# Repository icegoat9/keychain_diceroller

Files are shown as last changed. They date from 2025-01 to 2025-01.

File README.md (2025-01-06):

## Keychain Diceroller

I recently bought a board game that was missing a specialized die. Clearly the easiest solution to that problem was to build a little electronic keychain 'dice roller'.

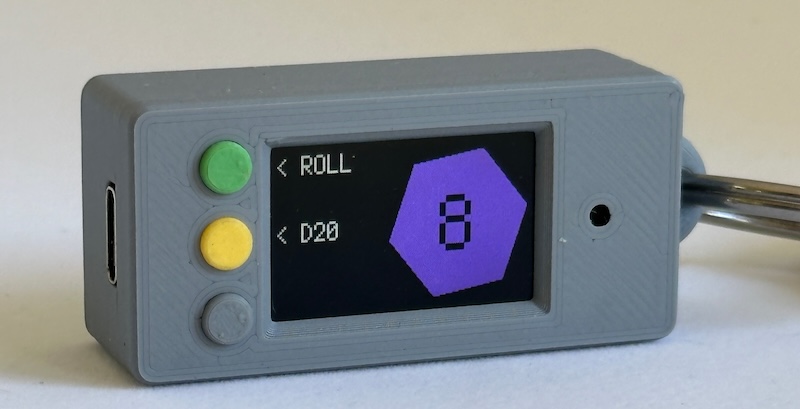
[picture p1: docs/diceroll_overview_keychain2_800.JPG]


<!-- demo video -->
https://github.com/icegoat9/diceroll_feather/assets/85364179/eb14111a-678f-439f-8b59-4e56392dd97d

**Features:**
* Press top button to roll a die
* Press middle button to cycle through a custom list of dice to roll (here: D3, D6, D10, D20, D100)
* Numbers on dice can be configured to start at 1 (D6, D20) or 0 (D10, D100)
* Dice can also display symbols (e.g. D3 rolls a "-", "O", or "+", for a specific game)
* Small battery that charges over USB-C port
* Standby battery life of many months (the system goes into a light sleep mode to save power after a short period of inactivity, and a deeper sleep mode after minutes of inactivity).
## Hardware

* Adafruit [ESP32-S3 Feather with reverse-mounted TFT](https://www.adafruit.com/product/5691)
* Various batteries, most recently [Lithium Ion Polymer Battery, 3.7V 400mAh](https://www.adafruit.com/product/3898)
* For cleaner packaging (requiring minor desoldering), JST surface mount straight header e.g. [JST B2B-PH-SM4-TB](https://www.digikey.com/en/products/detail/jst-sales-america-inc/B2B-PH-SM4-TB)
* [Case](case/) (3D printed, with button inserts)
  * Nominally, 2 each M2 and M2.5 BHCS fasteners, but a few dots of superglue may be easier...

## Development Log

Hooking together some parts I had laying around to experiment with this particular SPI-interface display and the CircuitPython ecosystem:

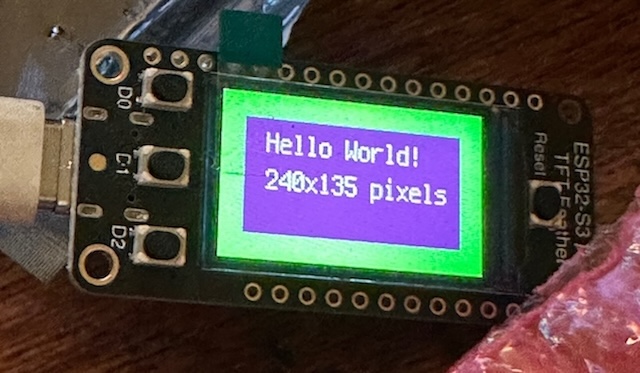
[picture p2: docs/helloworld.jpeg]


In a few hours I had a working battery-powered prototype I could use:

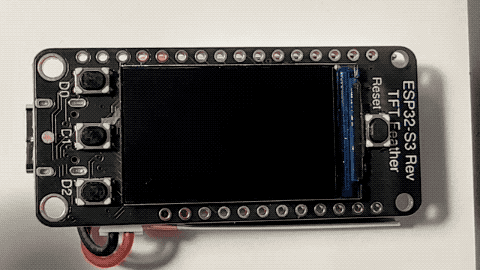
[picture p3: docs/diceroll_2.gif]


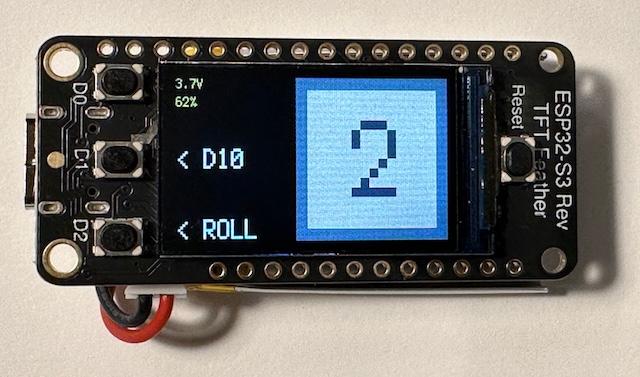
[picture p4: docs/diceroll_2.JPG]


However, the battery drained in about an hour-- that's not especially useful. I put the project on the back burner for a few weeks, but wrote some code to experiment with different power savings such as dimming or turning off the display, disabling unused peripherals, and various ESP32 sleep modes, and left prototypes running for days and weeks to log battery level over time:

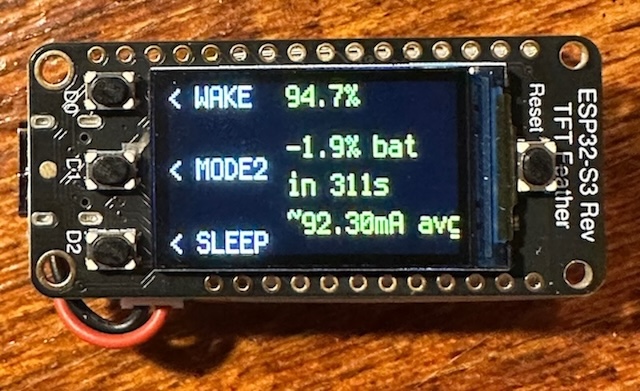
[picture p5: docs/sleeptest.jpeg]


For cleaner packaging than just "a PCB double-stick-taped to an unprotected LiPo battery", I prototyped a few cases. It was inconvenient that the battery needs to enter on the side of the PCB, so I carefully desoldered the right angle battery connector and replaced it with a straight through connector (I also desoldered the unused Stemma QT I2C connector on the back of the Feather to make more space for the battery):
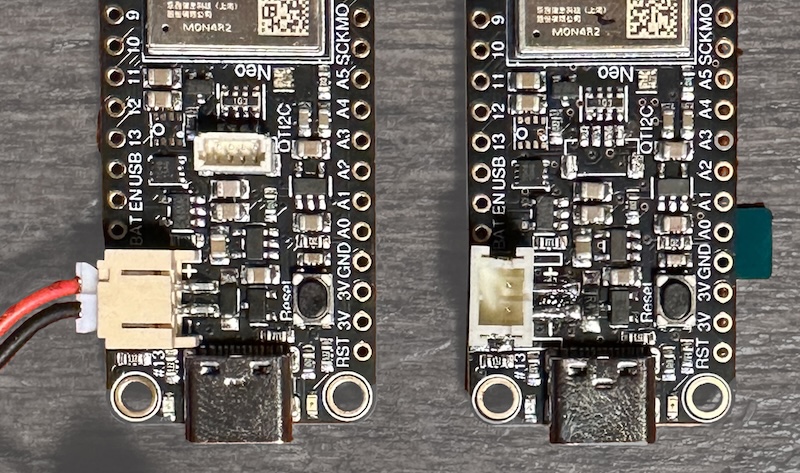
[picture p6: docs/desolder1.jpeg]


**CAUTION:** I had to bend the pins on this straight-through connector 180 degrees (shown below after bending), because soldering the off-the-shelf straight-through connector into the existing location would have swapped + and - relative to the right angle connector, frying the board! Be careful that the polarization notch on the connector is consistent between the removed right-angle and replacement connector:
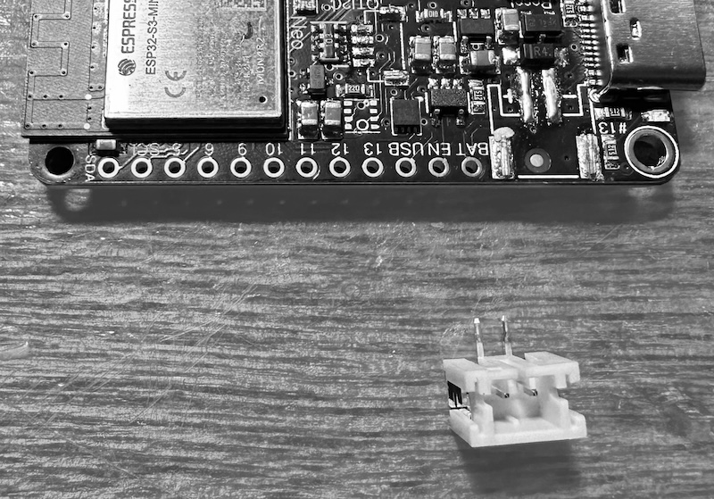
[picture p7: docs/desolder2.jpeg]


First PCB sandwich with a narrow 400mAh LiPo battery:
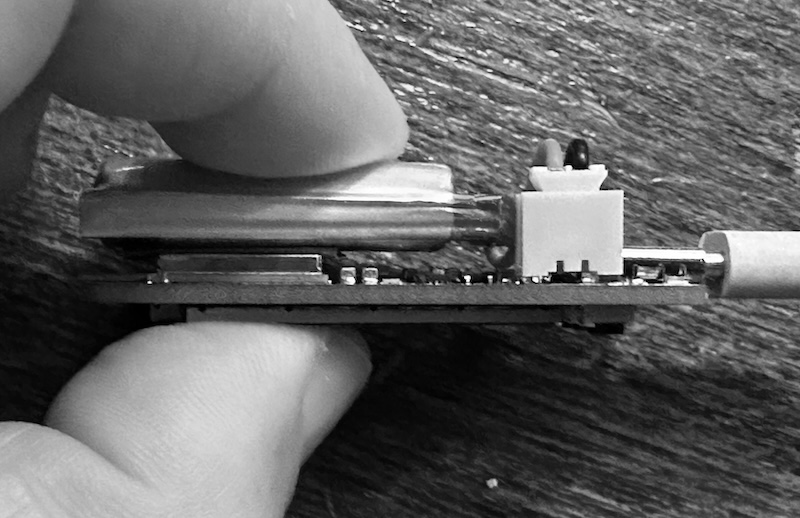
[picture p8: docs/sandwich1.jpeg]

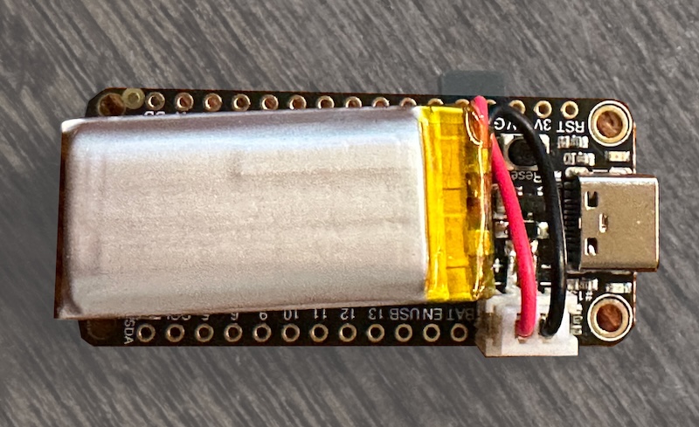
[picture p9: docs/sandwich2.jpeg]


A quick case design, 3D printed by a friend in PLA ("a polyester made from fermented plant starch"):
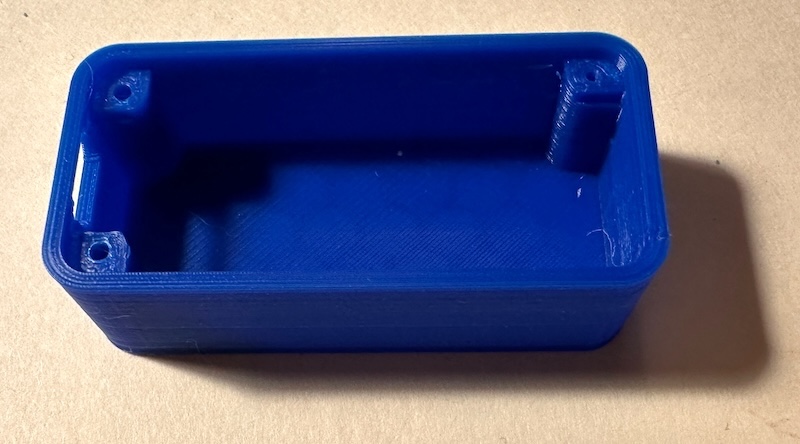
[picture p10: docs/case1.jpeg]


Tapping fine threads directly into 3D printed plastics is a bit sketchy as a design practice compared to pressing in metal inserts, but if you undersize the holes a bit, use a jig, and have deep enough threads, it's possible... and I have a finished-enough portable device:
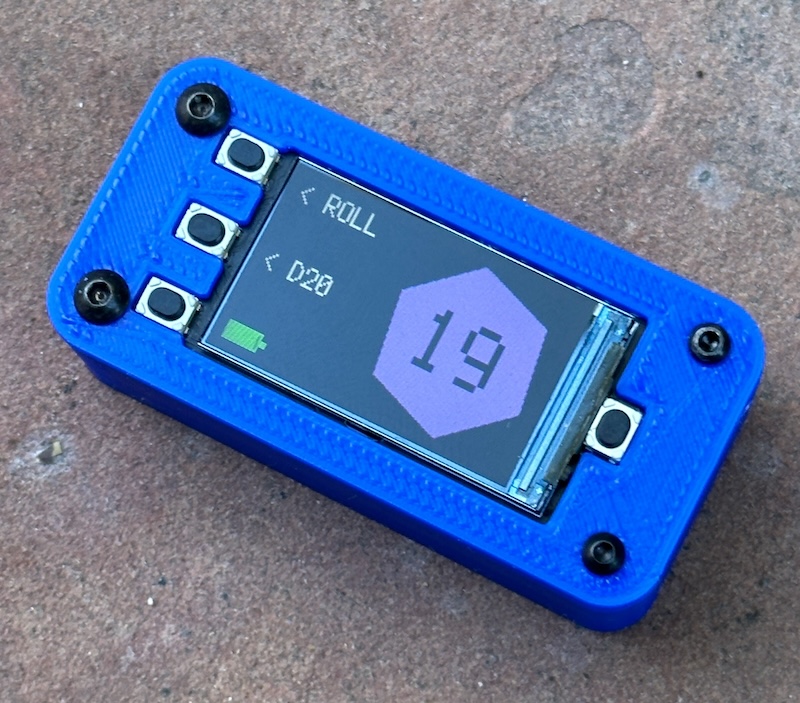
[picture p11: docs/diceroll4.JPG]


Finally, I came back to the software to add some light animations, a battery indicator, and a hybrid sleep mode for what should be months of battery life. This was a satisfying small project.

**v2 Update:**  

I put a bit more time into the project, mostly to design the new enclosure with buttons shown at the top of this page ([more details on the case design](case/)). I also took that opportunity to clean up and remove unused or debugging code and add a smarter battery icon.

The standby battery life seems excellent in practice-- over the past few months I've used this from time to time when playing a game (including the solo board game "Gloomhaven: Buttons & Bugs", which needs a special - / 0 / + die), and the battery finally ran down and needed a recharge after about six months (though it spent several of those months sitting unused).

## Installation

* Configure the Feather with CircuitPython 9.x
* Copy diceroll.py, code.py, and the lib/ folder onto the Feather

## Possible Future Work

This is 'good enough' for now, and I was trying to keep this a quick side project-- I don't expect to put more time into this unless inspiration strikes, but a few ideas I could come back to some day:

* ~~Revise the enclosure to cover the edges of the display, add button caps, and be less boxy overall~~
* ~~Buy my own 3D printer rather than depending on a friend's or paying every time I want to revise a design...~~
* Look into improving the performance of drawing vector shapes for a faster 'die rolling' animation
* Dig deeper into ESP32 sleep modes and ways to extend battery life outside of deep sleep-- battery life is already great, but perhaps this could enable an even smaller battery and package
* Add the ability to roll multiple dice at once (e.g. 2D6), including some visualization of each die, not just a total
* Add a whole configuration mode / menu (entered by the third button), to let you adjust parameters such as the sleep delay, the animation speed, the list of dice options, and so on, without having to edit and reload code
  * Persist all of these settings in backup RAM through deep sleeps, or maybe even to onboard flash when power is lost *(I don't really need any of these features, but menu+configuration+persistence could be useful in a future project...)*

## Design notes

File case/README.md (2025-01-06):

This folder contains the current STL files for three case variants:
1. A simple case variant that leaves some of the PCB exposed
2. A case with button inserts and rear fasteners for a cleaner look (note: tapping tiny threads into a PLA 3D print of this is very difficult-- I may redo in a different material or redesign to use press-in threaded inserts)
3. A quick variant on case #2 but with pins, to be glued together (simpler than dealing with threads for now)

## Details

A few steps from along the way...

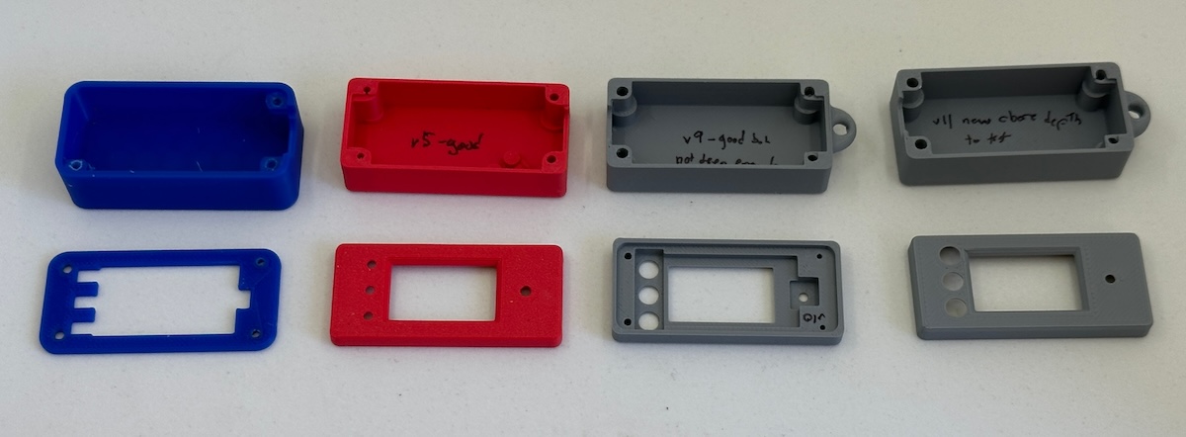
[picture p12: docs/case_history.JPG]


Design #1 is the simple case I got a friend to 3D print. It looked good enough:



Months later when I picked up my own 3D printer I was inspired to iterate on a design with button inserts and rear-mount fasteners:

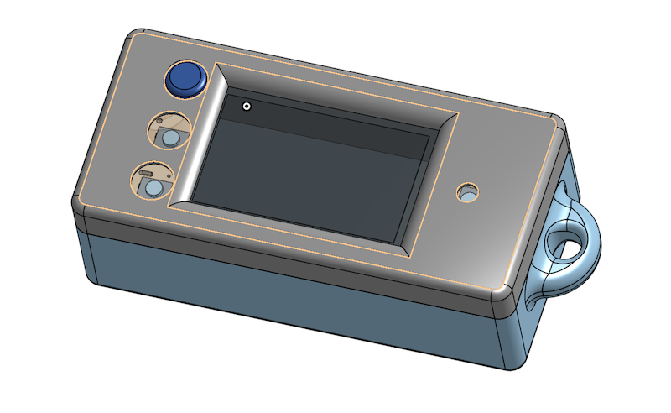
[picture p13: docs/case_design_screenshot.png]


The tolerances on a display's active pixel region relative to the edge of the glass or the display's mounting can be a challenge to design around in a volume product. For a one-off prototype it's easy enough to just display a test pattern and revise the part design until it lines up.

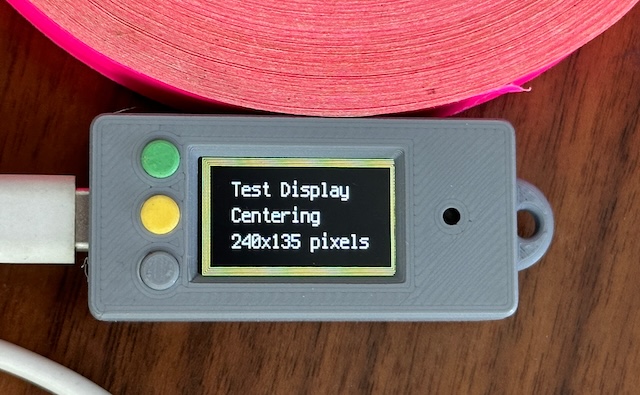
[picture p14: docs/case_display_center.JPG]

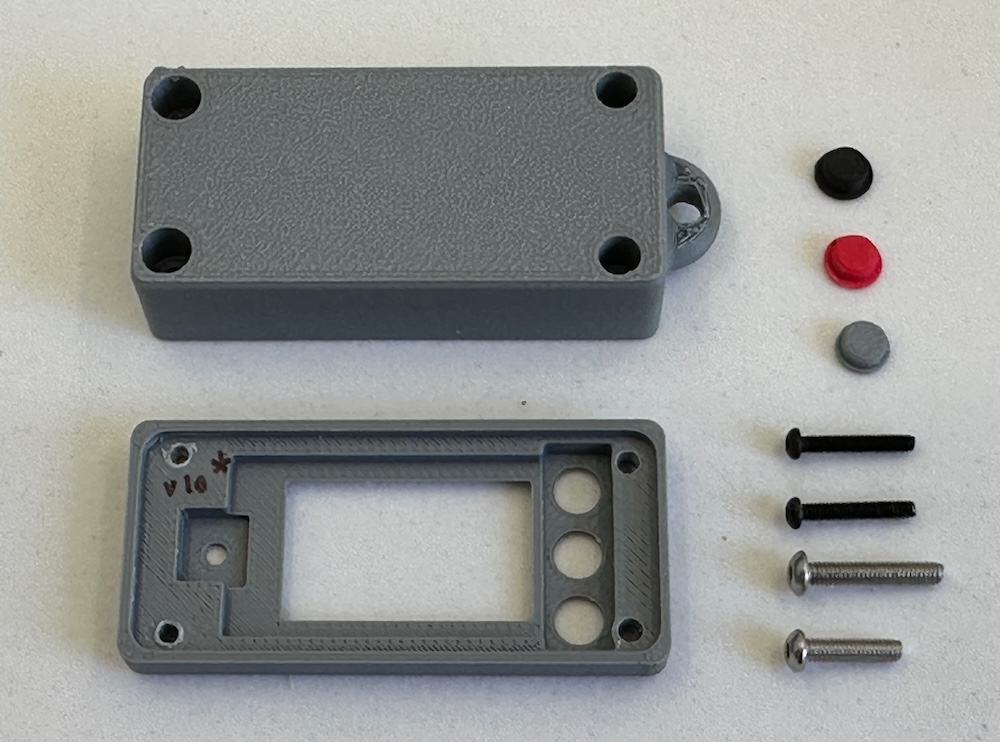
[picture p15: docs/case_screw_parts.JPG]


This case mostly works, but tapping M2 and M2.5 threads into 3D printed PLA is... not reliable, especially into these shallow blind holes. I have an M2.5 bottoming tap but don't have the equivalent in M2, and went through three copies of the top plate before I got 3/4 of the threads tapped well enough that it would assemble. Then I realized I was missing matching black oxide fasteners in the correct lengths.

I didn't want to wait to get new hardware, so I made a minor variant on it, with locating pins on the bottom piece that the PCB sits on rather than holes for screws. With a thin bead of cyanoacrylate it came together nicely, I'll just have to break it open if I ever want to service it. I could design a version with more robust heat-set threaded inserts, but it's not worth the time for this one-off.



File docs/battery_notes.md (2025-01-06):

### Battery usage experiments / scratchpad

Testing with a 420mAh LiPo battery (plan to use an even smaller one) using the MAX1704x i2c battery fuel gauge reported values:

With display on and active (Neopixel power is always off), presumably high power draw:
* 63% at 6:17pm
* 19% at 6:30pm
* Rough extrapolation (if battery meter and capacity are correct) suggests 44% drain / 13min = 184 mAh / 13min, ~850 mA!?
* At this high discharge rate (> 1C) using a smaller battery will be an issue...

With display and I2C powered down (but not using any microprocessor sleep mode, and WiFi / Bluetooth may be on in background? unclear):
* 39% at 5:15pm
* 27% at 5:28pm
* 25% at 5:30pm
* Rough extrapolation (if battery meter and capacity are correct) suggests 56% drain / hour or 235 mAh / hour = 235 mA!?
* At this moderately high discharge rate (~0.5C for this battery), using a much smaller battery may be an issue

Using microprocessor sleep modes (see [CircuitPython reference](https://learn.adafruit.com/deep-sleep-with-circuitpython/alarms-and-sleep)):

With microprocessor in light sleep (which should power down WiFi as well), and display and I2C powered down:
* 18% at 6:31pm
* "18%" at 6:35pm? though maybe battery meter hasn't kept up, if I2C power is down does that mean it's not tracking? hmm...
* 8% at 7:09pm
* This suggests 10% / 38min or 16% drain / hour or 66 mAh drain / hour, ~66mA!? (significantly higher than expected for sleep mode, maybe there are more peripherals to turn off...)

Second test:
* 94% at 9:10pm
* 84% at 9:48pm
* Suggests ~6hr lifetime, not great (~66mA draw estimated again-- something is still a big draw)

Third test, after adding `import wifi` and `wifi.radio.enabled = False` (not sure if that will change anything vs. not importing wifi in the first place?)
* 85% at 9:53pm
* 73% at 10:21pm
* Suggests ~25%/hr discharge or ~4hr lifetime, not notably different from without those wifi lines

Another test, now with D0 as trigger / wakeup pin, and fractional percent reporting
* 2:44pm 93.7% (surprisingly high given we were just at 69% recently and only briefly plugged in, I'm skeptical at first that it's this high)
* 3:15pm 76.3% (= 17.4% in 31min or about 35% capacity / hr or ~140mA estimated!? unless previous capacity was artificially high)
* 3:26pm 70.3$ (= 6% in 11min or ~36% / hr, again, hmm)

With microprocessor in deep sleep, and display and I2C powered down: (temporary test w/ D0 as wake pin instead of D2 for deep sleep...)
* 70% at 10:25pm 4/22
* 69% at 10:55pm (ooh, more promising...)
* 69% at 7:38am 4/23 (aha! still very long life... assuming battery gauge is still working... does it need more time to register?)
* 69% at 10:16am and 11:40am and 12:42pm and 2:30pm ! -- then stopped test. Not convinced I'm getting good data? TBD

Further sleep testing with dedicated test_power_usage.py: (**see photos taken 2024-04-23 of displayed results**):
* S0: ~107 mA
* S1: ~150 mA!? (doesn't make sense that this would be higher than S0... but only tested over the course of a few minutes, but maybe it's the S0 that's low)
* S2: ~130 mA!? averaged over 2400s (consistent with some earlier tests)

Further testing after recharging battery to near full
* S0: n/a (high, 100mA or more)
* S1: ~80mA? (but over just 5min so not much battery% delta to work with) 
* S2: mA? (but over just 5min so not much battery% delta to work with) 
* S3: mA? 

2024-04-27 long-running battery study involving systems waking themselves up every 30-60min to log battery state to on-board Flash (also means we don't need to directly depend on battery charge meter being correct, as we'll see when the device drains enough to stop logging):
* One device with 420mAh battery set to deep sleep for 1 hour, wake up for 1 second (plus boot-up so ~5s) and log to flash
  * Lasted multiple days, so left running
* One device with 400mAh battery set to light sleep (which has seemed ineffective) with TFT and I2C off for 30min, wake up for 1s to log to flash, repeat
  * Still only lasted 3.5 hours of light sleep

2024-May long-running battery study, with system that deep sleeps and wakes once an hour to log battery to on-board Flash, with pinAlarm also enabled (though not used) for comparable test to diceroll trinket:
* 420 mAh battery lost 14% in 20 days, suggesting months of deep sleep

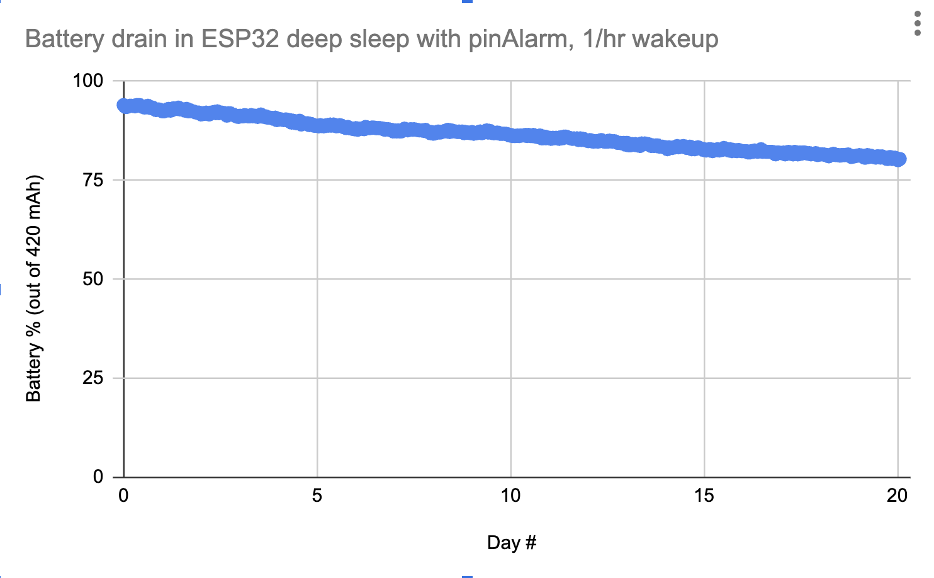
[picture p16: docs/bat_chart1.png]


The same test device was still alive as of ~early July (not used for past month), and was at ~50% battery?, so we do have many months of deep sleep if not in use, though it's not running identical code.

### Battery Packaging Dimensions

Feather relevant dimensions:
* 2.0" x 0.9" outer dimensions
* Two mounting holes are at 0.7" spacing, and are 3mm diameter holes (M2.5 or #4-40 screw), the other two are for M2 screws and are spaced differently but 1.8" away
* So, the rectangle fully inside of mounting holes in both directions would be at about 1.68" x 0.58"
  * Or 2.0 x 0.58 or 1.68 x 0.9" if we want a rectangle that clears mounting holes in one of the two directions and goes to board outline in the other
* There's just 1.4" length 'beyond the battery connector to the other end of board' (since battery connector is thick and we may want to avoid)
  * If we want to clear the mounting holes as well, we lose 0.16" so would have about 1.24" x 0.9" space

Small batteries sold by Adafruit:
* 500 mAh: 1.15 x 1.4 x 0.19"
* 420 mAh: 1.38" x 0.94" x 0.20"
* 400 mAh 1.41" x 0.67" x 0.31" (special "narrow for between feather headers", but thicker)
* 350 mAh  1.4" x 0.8" x 0.22"
* 350 mAh short cable  1.3" x 1.0" x 0.2"
* 150 mAh  0.77" x 1.02" x 0.14"
* 100 mAh  0.45" x 1.2" x 0.15"

So, what fits fully within the "rectangle that's within the mounting hole profile in one direction, and within board in the other?
* 100, 150, 350, 400narrow

Do any fit the "downstream of battery connector between that and mounting holes of 1.24 x 0.9"?
* 100, 150

None fit downstream of Stemma QT connector without also blocking mounting holes? But 150mAh probably just fits if it blocks those two holes...

If we're willing to only use three of the four mounting holes, though, and obstruct one of the smaller mounting holes with the battery, the 400mAh narrow battery should just fit.

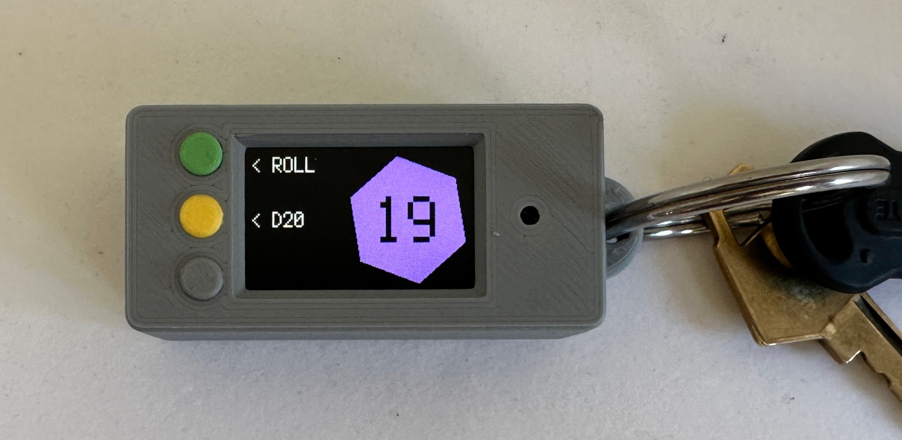
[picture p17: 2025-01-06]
docs/diceroll_overview_keychain.JPG

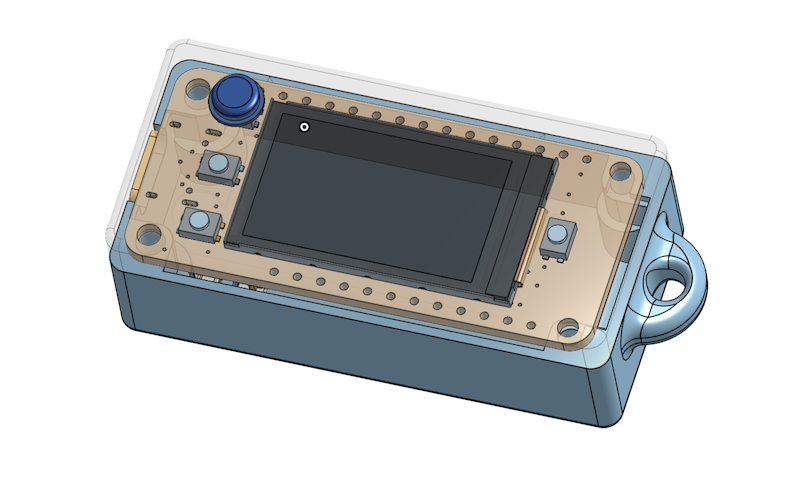
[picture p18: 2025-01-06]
docs/case_design_screenshot2.png

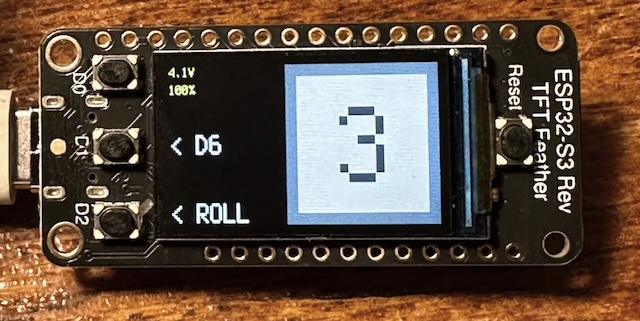
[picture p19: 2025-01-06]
docs/diceroll_1.JPG

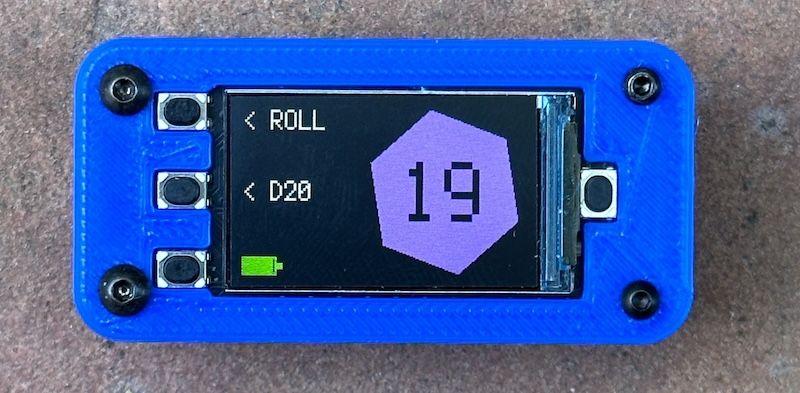
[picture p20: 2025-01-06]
docs/diceroll3.JPG

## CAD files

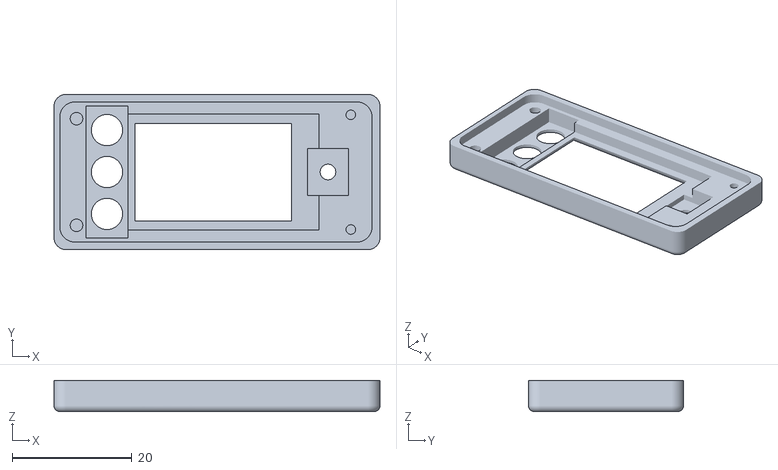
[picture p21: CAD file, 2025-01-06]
case/case_top_v12.stl
54.3 x 25.9 x 5.21

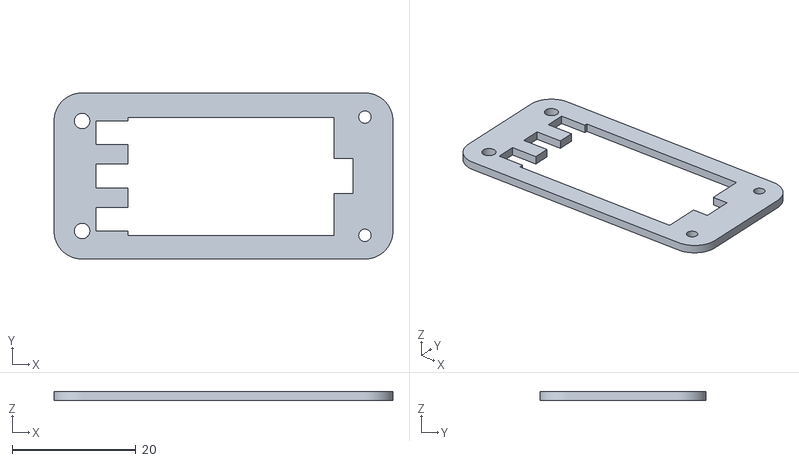
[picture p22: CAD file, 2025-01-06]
case/simple_case_top_v3.stl
54.8 x 26.9 x 1.50

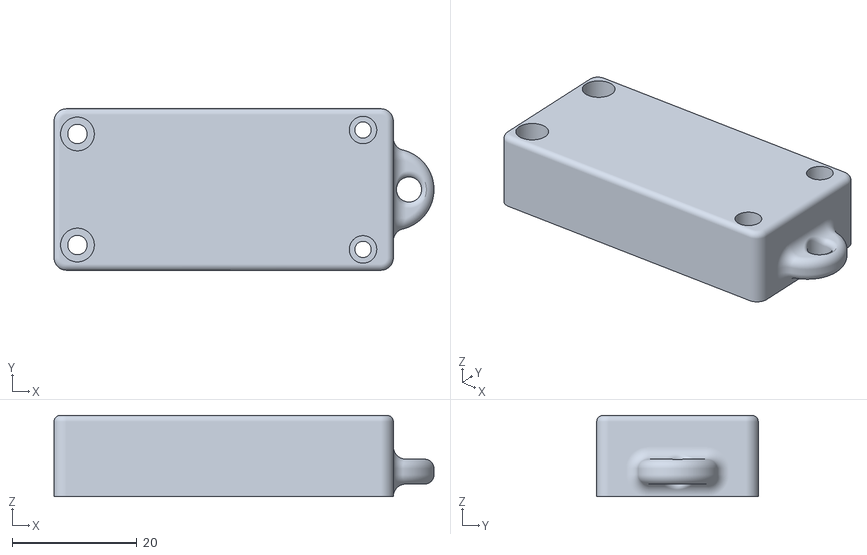
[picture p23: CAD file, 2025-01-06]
case/case_bottom_v12.stl
60.8 x 25.9 x 13.0

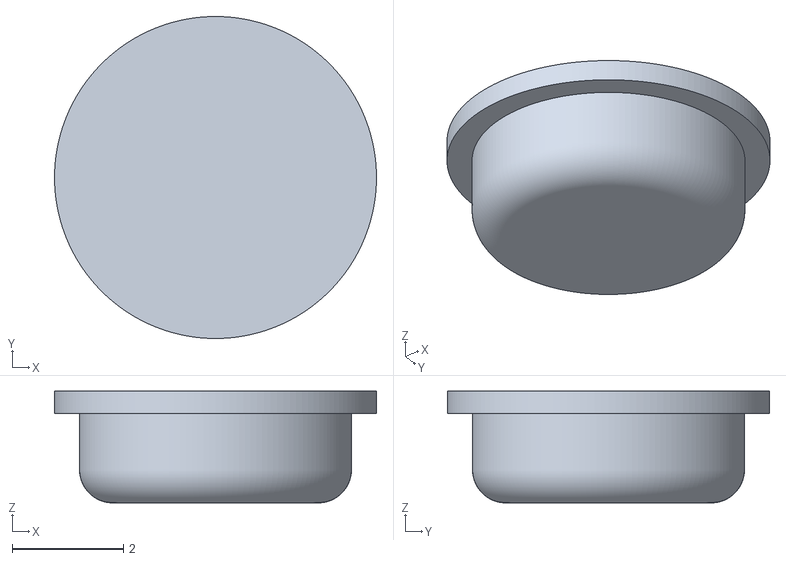
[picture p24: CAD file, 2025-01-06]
case/button.stl
5.80 x 5.80 x 2.01

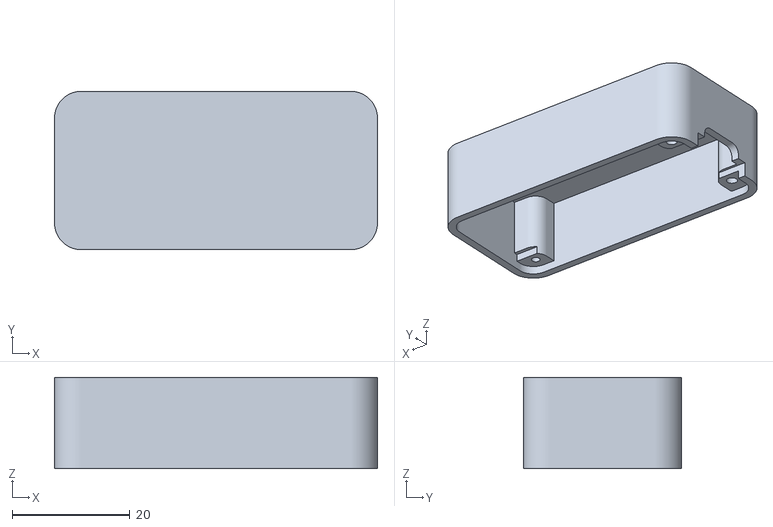
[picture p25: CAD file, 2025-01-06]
case/simple_case_bottom_v3.stl
54.8 x 26.9 x 15.5

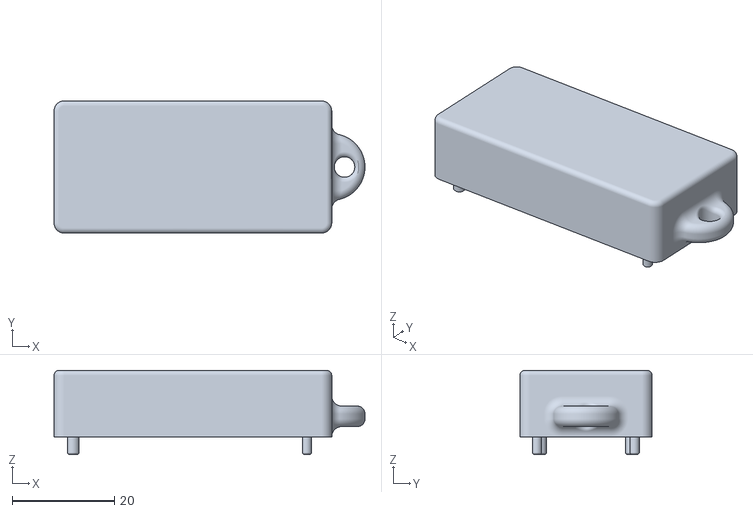
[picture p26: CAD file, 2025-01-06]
case/case_pinfit_bottom_v10.stl
60.8 x 25.9 x 16.5

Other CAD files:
case/case_pinfit_top_v11.stl

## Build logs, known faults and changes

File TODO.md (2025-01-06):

## diceroll_feather: Quick TODO list
```
[x] Core dice rolling and graphics proof of concept (test_diceroll.py)
[x] Read battery level and display (where?)
    Save power by...
[x]   Turning off display after N seconds
[x]   Going into actual processor sleep mode?
[x]   Sleep Memory for Deep Sleep
[x]   Debug deep sleep crash / restart on actual battery power (pullup issue, perhaps? happens w/ pullup set true or false)
[x]     Test using D0 (active low) as interrupt / wake pin instead in case this is something pullup related
[x]   **Create much simpler test case that just prints battery % to screen in larger font, and after waking from sleep
        also calculates "% drop in XX seconds since last button press" (e.g. 'press D1 to change sleep mode, D2 to initiative sleep, D0 to wake')
[x]   Test power draw in light sleep mode with D0 as wake pin (not sure why it would be different, just in case we're not fully sleeping?)
[ ]   Post on forums to ask about current draw seen in light sleep or with TFT off (once test case program implemented)
[x]   Rerun deep sleep logging test but with a pin alarm as well (since with pin alarm on, sleep draws more power than timer deep sleep per [this link](https://learn.adafruit.com/deep-sleep-with-circuitpython/power-consumption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))
[x]   Change backlight brightness on board for dim mode instead of changing colors
[x]   If the D0 deep wake works, swap UI so D0 rolls die?
[x]   Two-stage sleep: light sleep earlier, then deep sleep only after a few minutes? (do math on mA draw and life)
[x]     auto-roll die after waking from deep sleep!
[x]     or instead, save last_roll in sleep memory and display that (if last_roll: ...)
[x] Larger battery % font, no voltage
[x] Add battery icon (w/ red, yellow, green)
[x] Measure energy draw in various sleep modes...
[x] Maybe: debounce D2 (only trigger once on press) and instead 'animate' roll by cycling through values for some amount of time
           rather than depending on how long the user presses the button
[x] Add more animation of the roll? (N-sided dice polygon rotating, for example, especially if rotation is a primitive we have)
[x] Different polygon around die area based on D# (triangle for D3, square for D6, facet for D10/D20, etc) -- needs some thought
[x]   Should we erase the previously-rolled # (or change to ?) in that case so not confusing to see large D20 value in a D6?
[x] Select smaller battery
[x] Design simple case and order
[x] Test desoldering battery connector and replace with straight connector, and desoldering Stemma connector
[ ] Debug occasional graphical glitch with switching die: previous polygon not erased? (may be fixed now)
```
## Lower priority TODO
```
Software Features:
[ ] Figure out if it's possible to make the CircuitPython 'boot-up' less verbose (e.g. don't show on-screen boot text)
[ ] Add ability to roll '2D6' as an option
[ ]   (or another button to cycle through # to roll...? reset to 1 if first time used in a while? save to memory?)

Hardware Features:
[ ] Maybe: revise case to have USB C fit into surrounded slot not just cutout (need space for LEDs/resistors adjacent)
[x] Thicker top-plate that also hides edges of display
[x]   Separate (colorful) plastic button caps on each button (captured by this thicker top plate)
[x]   New rear-mount case design (with threads or inserts in rear of thicker top plate)
[ ] Look into availability of heat-set M2.5 and M2 threaded inserts / helicoils

Cleanup and test
[x] Refactor dieroll()
[ ] Precompute polygon vertices for animation, test to see if that speeds animation
    (either on dice type switch, or precompute all possible rotations in a big lookup table)
    (WIP: ran a few tests but not using, good enough for now)
[ ] Determine if initial black bitmap needed
[ ] Clean up palette assignment to objects (sometimes use three lines, not needed)
[ ] More variable renames e.g. gfx_ or obj_ or gfx_layer_, see notes in code
[x] Remove, comment out, or hide behind a "allow_sleepmode_change" global the unused sleep modes 
[ ] External power meter logging of current draw of each peripheral and sleep mode:
[ ]   Neopixel, I2C/TFT, backlight brightness, time.sleep duration, light/deep sleep, Wifi/bluetooth, etc
[ ] Remove TODOs from code
```

## Scratchpad / Notes

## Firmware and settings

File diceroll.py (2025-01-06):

# Roll virtual die on Feather (ESP32-S3 + SPI TFT display + battery)
# https://github.com/icegoat9/diceroll_feather

import alarm
import board
import displayio
import terminalio
import random
import time
import digitalio
import math
import vectorio

# For imports below here, need to copy the libraries from the circuitpython bundle to the local lib/ folder
from adafruit_display_text import label
import adafruit_max1704x

# does importing WiFi let us shut it off? (didn't make an obvious battery difference, though...)
# import wifi
# wifi.radio.enabled = False

TFT_BRIGHTNESS = 0.5
TFT_DIM_BRIGHTNESS = 0.1
INACTIVITY_DIM_TIME = 10
INACTIVITY_SLEEP_TIME = 15
INACTIVITY_DEEPSLEEP_TIME = 180  # the main power saving measure...

# Disable Neopixel to save power
neopixel_power = digitalio.DigitalInOut(board.NEOPIXEL_POWER)
neopixel_power.direction = digitalio.Direction.OUTPUT
neopixel_power.value = False

# Prepare to disable TFT (and Stemma QT) to save power
tft_i2c_power = digitalio.DigitalInOut(board.TFT_I2C_POWER)
tft_i2c_power.direction = digitalio.Direction.OUTPUT
# tft_i2c_power.value = False  # initially powered down, but will power up shortly
tft_i2c_power.value = True  # power up display and I2C (already on by default...)
low_power_mode = False

dice_types = [
    {"sides": 3, "zero_index": False, "polygon_sides": 3, "poly_r0": 0, "symbol_list": ["-", "O", "+"]},
    {"sides": 6, "zero_index": False, "polygon_sides": 4, "poly_r0": 45},
    #    {"sides": 6, "number": 2, "zero_index": False},
    {"sides": 10, "zero_index": True, "polygon_sides": 5, "poly_r0": 54},  # return 0-9, not 1-10
    {"sides": 20, "zero_index": False, "polygon_sides": 6, "poly_r0": 0},
    {"sides": 100, "zero_index": True, "polygon_sides": 10, "poly_r0": 0},
]

dice_index = 3  # D20

polygon_rotation = 0  # 0 to 360...
animation_running = False  # is a die roll currently animating?
ANIMATION_DURATION = 0.5

# if we just woke up from a deep sleep and reboot, load some config values from backup RAM / sleep memory
if alarm.wake_alarm:
    dice_index = alarm.sleep_memory[0]

# Battery monitor
monitor = adafruit_max1704x.MAX17048(board.I2C())

# Configure three input buttons
button_D0 = digitalio.DigitalInOut(board.D0)
button_D0.switch_to_input(pull=digitalio.Pull.UP)
button_D1 = digitalio.DigitalInOut(board.D1)
button_D1.switch_to_input(pull=digitalio.Pull.DOWN)
button_D2 = digitalio.DigitalInOut(board.D2)
button_D2.switch_to_input(pull=digitalio.Pull.DOWN)

# board-specific display initialization (for this S3 TFT Feather)
display = board.DISPLAY
display.brightness = TFT_BRIGHTNESS

## Button management and debouncing

def button_pressed(n):
    """Check if button N is pressed (implemented differently for D0 vs. D1/D2 due to board pullups vs pulldowns)"""
    if n == 0:
        # D0 is pulled HIGH by default on S3 Reverse TFT Feather (see docs)
        return not button_D0.value
    elif n == 1:
        return button_D1.value
    elif n == 2:
        return button_D2.value
    else:
        raise ValueError(f"No such button #{n}")


def any_button_pressed():
    return button_pressed(0) or button_pressed(1) or button_pressed(2)


def debounce_buttons():
    global debounce_D1
    if not button_pressed(1):
        debounce_D1 = False
    global debounce_D2
    if not button_pressed(2):
        debounce_D2 = False

debounce_D1 = False
debounce_D2 = False


############ WIP polygon rotation speed improvement idea (not yet used)
#   initial polygon configuration to minimize computation needed in the generate_polygon_pts() call below
#   TBD if this speeds it (is this math bottleneck or display interface?)
# TODO: copy much of this into a function called when we switch # of polygon sides and on startup...
# TODO: change this to a dict indexed by rotation angle [5], [10], etc?
# TODO: could generate different rotation densities per die type (e.g. large # side polygons rotate faster)
poly_radius_default = display.height / 2
poly_radius = poly_radius_default   # different if scaled
# configure only on change of number of sides in polygon
poly_sides = dice_types[dice_index]["sides"]
poly_sidelen = math.pi * display.height / (1.2 * poly_sides)  # approximation
poly_angle_internal = 360 / poly_sides
poly_pts_lookup = []
# generate a list of the N polygon verticies for all possible 5 degree initial rotation values?
for i in range(360/5):
    poly_pts = []
    for j in range(poly_sides):
        an = math.radians(5 * i + poly_angle_internal * j)
        x = poly_radius * math.cos(an)
        y = poly_radius * math.sin(an)
        poly_pts.append((int(round(x)), int(round(y))))
    poly_pts_lookup.append(poly_pts)

def lookup_polygon_pts(rotation=0):
    """Calculate vertices of polygon-- lookup a precomputed set for current polygon type, for given rotation."""
    return poly_pts_lookup[rotation // 5]
############### end WIP code

def generate_polygon_pts(n, rotation=0, scale=None, x_offset=0, y_offset=0):
    """Calculate vertices of polygon with N sides."""
    # TODO: perhaps don't re-calculate all of these every time called if that slows us down
    #       (can pre-calculate some only when we change die type to roll?)
    if scale:
        poly_radius = scale * poly_radius_default
    else:
        poly_radius = poly_radius_default
    sidelen = math.pi * display.height / (1.2 * n)  # approximation
    angle_internal = 360 / n
    # let's have angles read clockwise from the +X axis
    pts = []
    for i in range(n):
        an = math.radians(rotation + angle_internal * i)
        x = poly_radius * math.cos(an)
        y = poly_radius * math.sin(an)
        pts.append((int(round(x + x_offset)), int(round(y + y_offset))))
    return pts


def rolldie(dietype) -> str:
    """Roll the die specified by the data structure dietype (typically an item from dice_types[]), return string result."""
    n = random.randint(1, dietype["sides"])
    if dietype["zero_index"] or "symbol_list" in dietype:
        n -= 1
    if "symbol_list" in dietype:
        return dietype["symbol_list"][n]
    return str(n)

##################
## Display Layout

# Create an image group we can add elements to, and add that group to the display
# The display will now automatically handle updating the screen with all objects in this group
display_group = displayio.Group()
display.root_group = display_group

# Next we create a Bitmap which is like a canvas that we can draw on.
canvas = displayio.Bitmap(display.width, display.height, 1)
# TODO: rename all these with some common prefix such as obj_ or layer_ or gfx_, to make later editing of these globals more clear?
# We create a Palette with one color and set that color to a value
background_palette = displayio.Palette(1)
background_palette[0] = 0x000000  # Black
# With all those pieces in place, we create a TileGrid by passing the bitmap and palette and draw it at (0, 0) which represents the display's upper left.
background = displayio.TileGrid(canvas, pixel_shader=background_palette, x=0, y=0)
display_group.append(background)

# Now draw the die icon background (filled polygon) on the right
DIEROLL_X0 = display.width - display.height
poly_palette = displayio.Palette(1)
poly_palette[0] = 0xCF50FA  # purple
current_die = dice_types[dice_index]
poly_points = generate_polygon_pts(current_die["polygon_sides"], rotation=current_die["poly_r0"])
polygon = vectorio.Polygon(
    pixel_shader=poly_palette, points=poly_points, x=DIEROLL_X0 + display.height // 2, y=display.height // 2
)
display_group.append(polygon)

# initial die value (and do a first roll on startup or resume from deep sleep)
DIE_TEXT_SCALE = 6
text_roll_color = 0x000000
text_roll_area = label.Label(terminalio.FONT, text="??", color=text_roll_color)
text_width = text_roll_area.bounding_box[2] * DIE_TEXT_SCALE
text_roll = displayio.Group(
    scale=DIE_TEXT_SCALE, x=DIEROLL_X0 + display.height // 2 - text_width // 2 + 6, y=display.height // 2
)
text_roll.append(text_roll_area)
display_group.append(text_roll)

def roll_die_and_update_display():
    text_roll[0].text = rolldie(dice_types[dice_index])
    # note: bounding_box = (x, y, width, height)
    text_width = text_roll_area.bounding_box[2] * DIE_TEXT_SCALE
    text_roll.x = DIEROLL_X0 + display.height // 2 - text_width // 2

def clear_die_display():
    text_roll[0].text = ""

roll_die_and_update_display()

## Menu text by buttons

text_D0 = displayio.Group(scale=2, x=0, y=10)
text = "< ROLL"
text_area = label.Label(terminalio.FONT, text=text, color=0xFFFFFF)
text_D0.append(text_area)
display_group.append(text_D0)

text_D1 = displayio.Group(scale=2, x=0, y=display.height // 2)
text_placeholder = "< D?"
text_area = label.Label(terminalio.FONT, text=text_placeholder, color=0xFFFFFF)
text_D1.append(text_area)

# Update D1 text with current die value
def set_display_die_info():
    text_D1[0].text = f"< D{dice_types[dice_index]['sides']}"

set_display_die_info()
display_group.append(text_D1)

## Battery % reading and display

def get_battery():
    """Return battery %, clamped from 0 to 100"""
    return max(0, min(100, monitor.cell_percent))

def get_battery_color(pct):
    if pct <= 20:
        return 0xFF0000  # red
    elif pct <= 70:
        return 0xFFFF00  # yellow
    else:
        return 0x00FF00  # green

# Battery visual icon
bat_icon = displayio.Group()
bat_icon_palette = displayio.Palette(1)

# get battery info
bat_level = get_battery()  # - random.randint(0,100)  # temporary random # for testing range of values
bat_color = get_battery_color(bat_level)

# Draw frame of battery as filled polygon
BXY = 3   # battery offset from display edge
BH = 15  # battery icon height
BW = 35  # battery icon width
BS = BH // 3  # battery step
BG = 2  # battery gap
BAT_THRESH_HIDE = 70
bat_icon_palette = displayio.Palette(1)
bat_icon_palette[0] = bat_color
bat_icon_frame = vectorio.Polygon(
    pixel_shader=bat_icon_palette,
    points=[
        (0, 0),
        (BW - BS, 0),
        (BW - BS, BS),
        (BW, BS),
        (BW, BS * 2),
        (BW - BS, BS * 2),
        (BW - BS, BS * 3),
        (0, BS * 3),
    ],
    x=BXY,
    y=display.height - BH - BXY,
)

# now clear out part of the battery w/ a black rectangle
black_palette = displayio.Palette(1)
black_palette[0] = 0x000000
fill_width = max(1, int((BW - BS - 2 * BG) * (100 - bat_level) / 100))
bat_icon_filling = vectorio.Rectangle(
    pixel_shader=black_palette,
    width=fill_width,
    height=BH - 2 * BG,
    x=BW - BS - BG - fill_width + BXY,
    y=display.height - BH + BG - BXY,
)

bat_icon.append(bat_icon_frame)
bat_icon.append(bat_icon_filling)

def update_battery_icon(bat_level = None):
    # update length and color of battery icon based on actually battery level
    # if a battery level was not passed to this function (e.g. for debugging), read it directly
    # TODO: remove some redundant layout code above since we call this function
    if not bat_level:
        bat_level = get_battery()
    # hide icon if battery nearly full
    bat_icon.hidden = (bat_level >= BAT_THRESH_HIDE)
    # update palette used for existing battery icon
    bat_icon_palette[0] = get_battery_color(bat_level)
    # update size and location of '% battery drained' black bar
    fill_width = max(1, int((BW - BS - 2 * BG) * (100 - bat_level) / 100))
    bat_icon_filling.width = fill_width
    bat_icon_filling.x = BW - BS - BG - fill_width + BXY

update_battery_icon()
display_group.append(bat_icon)

## Power management and sleep functionality

def enter_low_power():
    # Turn off display to save a bit of power
    global low_power_mode
    low_power_mode = True
    tft_i2c_power.value = False


def exit_low_power():
    global low_power_mode
    low_power_mode = False
    tft_i2c_power.value = True
    display.brightness = TFT_BRIGHTNESS

# handle dimming and sleeping after periods of inactivity
last_button_time = time.monotonic()

def time_since_last_button():
    return time.monotonic() - last_button_time

def deep_sleep():
    # save a few key status values to backup RAM ('sleep memory') to reload after deep sleep reboot
    alarm.sleep_memory[0] = dice_index
    button_D0.deinit()
    pin_alarm = alarm.pin.PinAlarm(pin=board.D0, value=False, pull=True)
    alarm.exit_and_deep_sleep_until_alarms(pin_alarm)
    # will never reach this point: reboots after exiting deep sleep

### Animation dieroll globals

def start_dieroll():
    global animation_running
    global animation_ticks
    global animation_t0
    animation_running = True
    animation_ticks = 0
    animation_t0 = time.monotonic()

### Roll the die on startup

start_dieroll()


# main program loop
while True:
    # D2 = reserve for future use (TODO? change number of dice to roll)
    if button_pressed(2):
#        update_battery_icon(random.randint(0,100))   # debug for testing
#        while button_pressed(2):
#            pass
        pass
    #### Low Power Mode: just check for wakes or need to deep sleep
    if low_power_mode:
        if time_since_last_button() > INACTIVITY_DEEPSLEEP_TIME:
            deep_sleep()
            raise RuntimeError("Unreachable code: deep sleep should have rebooted on wake.")
        if any_button_pressed():
            exit_low_power()
            while button_pressed(1) or button_pressed(2):
                pass  # wait until D1 or D2 released, but D0 will trigger a new roll, below
            last_button_time = time.monotonic()  # reset sleep timer once no longer pressing a button
    else:
        ### Standard Main Loop, if not in low power mode:
        if animation_running:
            # While animating a die roll, skip most other main loop code for speed, though can still check for changing dice
            polygon_rotation = (polygon_rotation + 10) % 360
            polygon.points = generate_polygon_pts(dice_types[dice_index]["polygon_sides"], rotation=polygon_rotation)
            # only update number every N animation cycles
            if (animation_ticks % 2) == 0:
                roll_die_and_update_display()
            animation_ticks += 1
            if time.monotonic() - animation_t0 > ANIMATION_DURATION:
                animation_running = False
                while button_pressed(0):
                    pass  # wait until D0 released if not already
        else: # Animation Not Running
            if any_button_pressed():
                display.brightness = TFT_BRIGHTNESS
                last_button_time = time.monotonic()
            if button_pressed(0):
                start_dieroll()
            # Read battery value and update icon
            update_battery_icon()
            # If no button has been pressed in a while, turn off display and I2C to save battery
            if time_since_last_button() > INACTIVITY_SLEEP_TIME:
                enter_low_power()
            elif time_since_last_button() > INACTIVITY_DIM_TIME:
                # dimming display: likely doesn't save much power, but cues user display is about to sleep
                display.brightness = TFT_DIM_BRIGHTNESS
        # Change which die to roll:
        #  Can even do this during an ongoing roll automation (restarts animation timer)
        if button_pressed(1) and not debounce_D1:
            clear_die_display()
            debounce_D1 = True
            dice_index = (dice_index + 1) % len(dice_types)
            current_die = dice_types[dice_index]
            set_display_die_info()  # updates text label based on global current_die
            # update background polygon
            polygon_rotation = current_die["poly_r0"]
            polygon.points = generate_polygon_pts(current_die["polygon_sides"], rotation=polygon_rotation)
            last_button_time = time.monotonic()
            start_dieroll()
        debounce_buttons()
    time.sleep(0.01)

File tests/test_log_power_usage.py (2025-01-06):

# Test approximate power / energy usage in different sleep modes via sleep, wake, and report over (serial, etc)
# Using MAX1704x battery gauge reported % battery capacity

# Log to flash by holding down D2 during boot (and installing the matching boot.py -- see datalogger_boot.py)

import alarm
import board
import displayio
import terminalio
import time
import digitalio

# For imports below here, need to copy the libraries from the circuitpython bundle to the local lib/ folder
from adafruit_display_text import label
import adafruit_max1704x

# does importing wifi let us shut it off? (didn't make an obvious battery difference, though...)
# import wifi
# wifi.radio.enabled = False

sleep_mode = 3  # S0 = no sleep, S1 = only turn off display / I2C, S2 = also microprocessor light sleep, S3 = also microprocessor deep sleep, S4 = hybrid (n/a)
SLEEP_TIME = 3600  # wake after ## seconds sleep and log battery level
WAKE_TIME = 1  # after waking for ## seconds (w/ display on), go to sleep

# Battery monitor
monitor = adafruit_max1704x.MAX17048(board.I2C())

# Configure inputs
# D0: wake-from-sleep (active low)
# button_D0 = digitalio.DigitalInOut(board.D0)
# button_D0.switch_to_input(pull=digitalio.Pull.UP)
# D1: change sleep mode
button_D1 = digitalio.DigitalInOut(board.D1)
button_D1.switch_to_input(pull=digitalio.Pull.DOWN)
# D2: was used during boot to enable storage...
# button_D2 = digitalio.DigitalInOut(board.D2)
# button_D2.switch_to_input(pull=digitalio.Pull.DOWN)

# basic board LED
led = digitalio.DigitalInOut(board.LED)
led.direction = digitalio.Direction.OUTPUT

# Disable Neopixel to save power
neopixel_power = digitalio.DigitalInOut(board.NEOPIXEL_POWER)
neopixel_power.direction = digitalio.Direction.OUTPUT
neopixel_power.value = False

# Prepare to disable TFT (and Stemma QT) to save power
tft_i2c_power = digitalio.DigitalInOut(board.TFT_I2C_POWER)
tft_i2c_power.direction = digitalio.Direction.OUTPUT
tft_i2c_power.value = True  # unnecessary as defaults on, but we can set to False to save power
low_power_mode = False

# Display setup
display = board.DISPLAY
display_group = displayio.Group()
display.root_group = display_group

# Menu text
# text_D0 = displayio.Group(scale=2, x=0, y=10)
# text_D0.append(label.Label(terminalio.FONT, text="< WAKE", color=0xFFFFFF))
# display_group.append(text_D0)

text_D1 = displayio.Group(scale=2, x=0, y=display.height // 2)
text_D1.append(label.Label(terminalio.FONT, text=f"< MODE{sleep_mode}", color=0xFFFFFF))
display_group.append(text_D1)

text_cycle = displayio.Group(scale=2, x=100, y=display.height // 2)
text_cycle.append(label.Label(terminalio.FONT, text=f"wake {WAKE_TIME}s, \nsleep {SLEEP_TIME}s", color=0xFFFFFF))
display_group.append(text_cycle)

# Battery level text
text_bat = displayio.Group(scale=2, x=100, y=10)
text_bat.append(label.Label(terminalio.FONT, text=f"{monitor.cell_percent:.1f}%", color=0xFFFF00))
display_group.append(text_bat)

low_power_mode = False


def enter_low_power():
    global low_power_mode
    low_power_mode = True
    tft_i2c_power.value = False


def exit_low_power():
    global low_power_mode
    low_power_mode = False
    tft_i2c_power.value = True


def log_battery_level():
    try:
        with open(f"/battery_log_{sleep_mode}.txt", "a") as log:
            # write time in seconds and cell percent to file
            log.write(f"{sleep_mode},{time.time()},{monitor.cell_percent}\n")
            log.flush()
            led.value = True
            time.sleep(0.1)
            led.value = False
    except OSError as e:  # Filesystem not writable by CircuitPython...
        print("error writing to filesystem")
        led.value = True
        time.sleep(1)
        led.value = False


lastsleep = time.time()

# if we just woke up from a deep sleep and reboot reset sleep mode from saved value
if alarm.wake_alarm:
    sleep_mode = alarm.sleep_memory[0]
    text_D1[0].text = f"< MODE{sleep_mode}"

# log battery level on startup (including if we just woke from a deep sleep and reboot)
log_battery_level()

while True:
    if not low_power_mode:
        # update battery text (but not if in low power mode with display off)
        text_bat[0].text = f"{monitor.cell_percent:.1f}%"
        # D1: change sleep mode
        if button_D1.value:
            sleep_mode = (sleep_mode + 1) % 4
            text_D1[0].text = f"< MODE{sleep_mode}"
            while button_D1.value:
                pass  # wait until it's no longer pressed
        # sleep on timer
        if (time.time() - lastsleep) > WAKE_TIME:
            # go to sleep
            lastsleep = time.time()
            # In any sleep mode except S0, turn off the display and I2C
            if sleep_mode >= 1:
                enter_low_power()
            # in more advanced sleep modes, sleep microprocessor
            # Sleep Mode 2: light sleep
            if sleep_mode == 2:
                pin_alarm = alarm.pin.PinAlarm(pin=board.D0, value=False, pull=True)
                time_alarm = alarm.time.TimeAlarm(monotonic_time=time.monotonic() + SLEEP_TIME)
                # Sleep with both time and pin alarms for more realistic power draw (pin alarm is what end app uses and draws more power)
                alarm.light_sleep_until_alarms(time_alarm, pin_alarm)
                # after sleep ends
                exit_low_power()
                lastsleep = time.time()
                log_battery_level()
            # Sleep Mode 3: deep sleep
            if sleep_mode == 3:
                pin_alarm = alarm.pin.PinAlarm(pin=board.D0, value=False, pull=True)
                time_alarm = alarm.time.TimeAlarm(monotonic_time=time.monotonic() + SLEEP_TIME)
                alarm.sleep_memory[0] = sleep_mode
                # Sleep with both time and pin alarms for more realistic power draw (pin alarm is what end app uses and draws more power)
                alarm.exit_and_deep_sleep_until_alarms(time_alarm, pin_alarm)
                # note: never reaches this line (processor reboots after wake from deep sleep, see if alarm.wake: line earlier)
    elif low_power_mode:  # only for sleep mode 1
        if (time.time() - lastsleep) > SLEEP_TIME:
            exit_low_power()
            lastsleep = time.time()
            log_battery_level()
    # loop after sleeping
    time.sleep(0.05)
